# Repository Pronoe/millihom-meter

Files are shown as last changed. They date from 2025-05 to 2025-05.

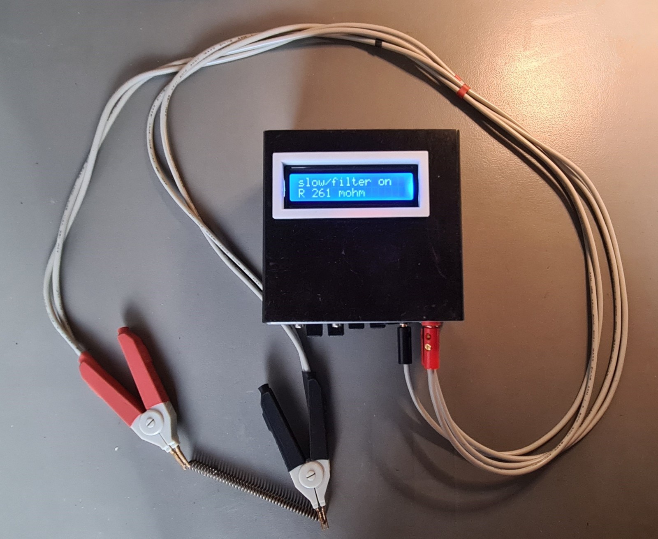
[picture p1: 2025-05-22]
pictures/20250522_191826 (FILEminimizer).jpg

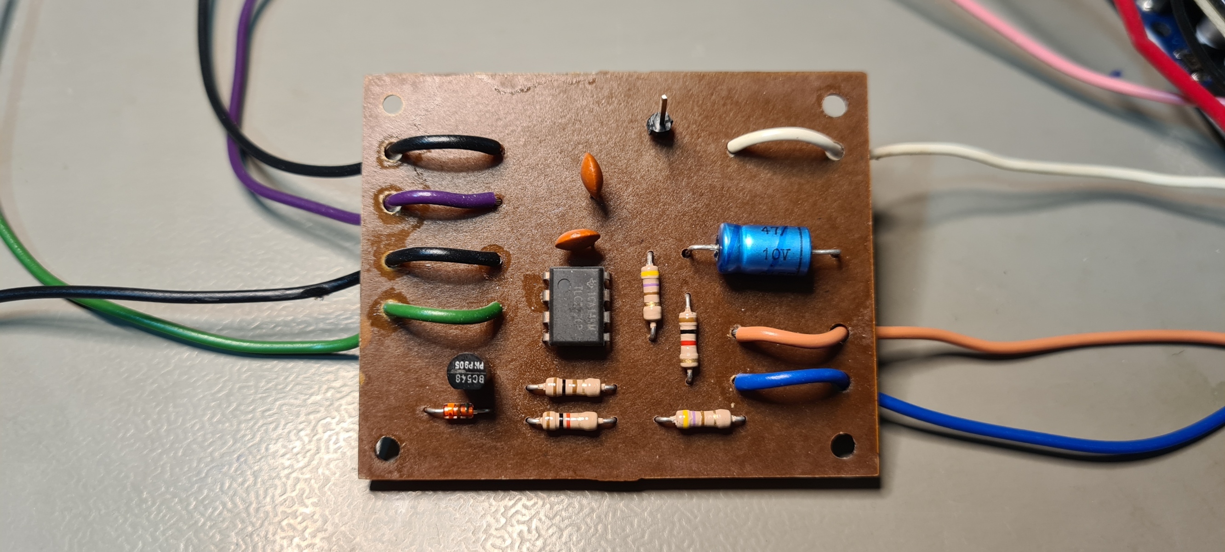
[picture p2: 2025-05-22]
pictures/20250503_223140 (FILEminimizer).jpg

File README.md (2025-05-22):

# milliohm-meter
Portable and low cost milliommeter with good performances

# Introduction
When you have to debug electronic systems or find failure on an electronic board or electrical system, you frequently need to locate short circuits.
Common multimeters  are generally limited down to 1 ohm in their measurement and this is not sufficient for efficient characterization and localization of a short circuit.
Below the 1 ohm domain, a milliohmmemeter is the required instrument but Industrial miiliohmmeters are expensive so I decided to build my own device.

# General design
I had viewed a good publication for a DIY milliohmmeter from the "Electro-bidouilleur" YouTube channel. The Elektor magazine sells also a add-on device for multimeters.
However this projects suffers several drawbacks:
-	need a separate multimeter for the measurement
-	provides no protection against excessive voltage on the device under test
-	do not use 4 wires measurement for better accuracy
The main characteristics of my design are:
-	use of a INA199 from Texas Instrument for the measurement
o	this is a Voltage-Output, Current-Shunt Monitor which need no additional component
o	provides very low offset voltage and very low drift
o	high accuracy gain
-	current source of 10.6 mA build with a ½ TLC272 which is a precision dual operational amplifier
-	voltage limiter with a BC548 transistor
-	use of and Arduino Uno board for:
o	output voltage measurement,
o	resistance computation from voltage measurement
o	initial zero compensation
o	full range calibration
-	use of a 2 lines x 16 characters LCD display shield for user interface
-	use of a a 1200 mAh LiPo battery combined with a step up converter/ battery charger  for portable operation
-	use of a "Kelvin" 4 wires cable for device connection

see detailed information in technical files

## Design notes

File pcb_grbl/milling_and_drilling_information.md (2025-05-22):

# Usinage PCB ampli milliohmmetre
Dimensions PCB : 61.6 x 48.9 mm
Entraxe trous de fixation : 54.0 x 41.3 mm
Routage PCB finalisé avec Kicad le 09/04/25
Prise en compte amélioration pads pour fil plus large, réutilisation maquette PCB INA199
Largeur piste 0.6 sauf au voisinage du INA199 : 0.4 mm
Isolation min : 0.4 mm
Utilisation plans de masse et Vcc avec isolation 0.4 mm.
Fichiers cnc générés avec Flatcam le 09/04/25, repris le 26/04/25 suite à 3 pistes oubliées dans Kicad
Fichiers gcode contrôlés avec utilitaire python le 09/04/25, recontrôlés le 26/04/25
Fichiers d'entrée Flatcam tournés de 90° pour que l'axe Y soit selon la plus grande longueur.
Origine usinage : en bas à gauche du PCB

# A faire dans cet ordre :
- fixer le PCB
- passer en mode avion
- charger PCB_milli-Edge_Cuts.gbr_cutout.nc pour avoir les contours du circuit
- faire le zero X et Y et noter le 0 machine
- monter fraise javelot et la sonde Z, faire le 0Z
- faire le height map après avoir validé auto pour reconnaitre les contours
- enlever la sonde Z
- appliquer couche d'huile
- lancer PCB_milli-B_Cu.gbr_iso.nc avec fraise javelot => isolation des pistes en 4 passes
- lancer PCB_milli-B_Cu.gbr_ncc.nc avec fraise javelot => nettoyage petits ilots de cuivre
- monter foret 0.8 mm et la sonde Z et faire le 0Z
- enlever la sonde Z
- lancer PCB_milli-PTH.drl_cnc_0.8.nc => perçage trous 0.8 mm
- monter foret 1 mm et la sonde Z et faire le 0Z
- enlever la sonde Z
- lancer PPCB_milli-PTH.drl_cnc_1.0.nc => perçage trous 1.0 mm
- monter foret 1.25 mm et la sonde Z et faire le 0Z
- enlever la sonde Z
- lancer PCB_milli-PTH.drl_cnc_1.25.nc => perçage trous 1.25 mm
- monter foret 2.5 mm et la sonde Z et faire le 0Z
- enlever la sonde Z
- lancer PCB_milli-PTH.drl_cnc_2.5.nc => perçage trous 2.5 mm
- monter foret 3 mm et la sonde Z et faire le 0Z
- enlever la sonde Z
- lancer PCB_milli-PTH.drl_cnc_3.0.nc => perçage trous 3.0 mm
- monter fraise corm shaped 0.95 et la sonde Z et faire le 0Z
- enlever la sonde Z
- lancer PCB_milli-Edge_Cuts.gbr_cutout.nc : découpe du PCB

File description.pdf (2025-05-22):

Introduction

When you have to debug electronic systems or find failure on an electronic board or electrical system, you frequently need to locate short circuits.

Common multimeters are generally limited down to 1 ohm in their measurement and this is not sufficient for efficient characterization and localization of a short circuit.

Below the 1 ohm domain, a milliohmmemeter is the required instrument but Industrial miiliohmmeters are expensive so I decided to build my own device.

General design

I had viewed a good publication for a DIY milliohmmeter from the "Electro-bidouilleur" (https://www.youtube.com/watch?v=fWgxbTQs47s&list=LL&index=22) YouTube channel. The Elektor magazine sells also a add-on device for multimeters.

However this projects suffers several drawbacks:

- need a separate multimeter for the measurement
- provides no protection against excessive voltage on the device under test
- do not use 4 wires measurement for better accuracy

The main characteristics of my design are:

- use of a INA199 from Texas Instrument for the measurement
- this is a Voltage-Output, Current-Shunt Monitor which need no additional component
- provides very low offset voltage and very low drift
- high accuracy gain
- current source of 10.6 mA build with a ½ TLC272 which is a precision dual operational amplifier
- voltage limiter with a BC548 transistor
- use of and Arduino Uno board for:
- output voltage measurement,
- resistance computation from voltage measurement
- initial zero compensation
- full range calibration
- use of a 2 lines x 16 characters LCD display shield for user interface
- use of a a 1200 mAh LiPo battery combined with a step up converter/ battery charger for portable operation
- use of a "Kelvin" 4 wires cable for device connection

Design details

One of the difficulties is that the INA199 is available only in a tiny SMD SC70 package and as I wanted to test the design with a breadboard, I had to build a SC70 adaptor to connect the INA199 to my breadboard.

I have made this adaptor by milling a PCB with a CNC 3018. Meanwhile I was also testing the ability to implement a SC70 adaptor with such a limited machine as the CNC 3018.

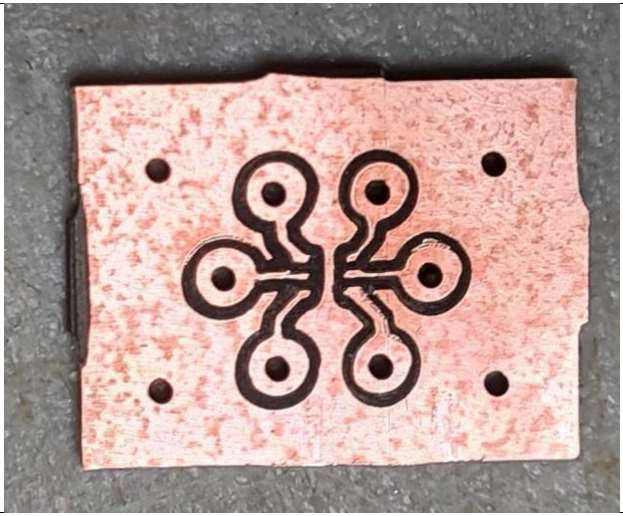
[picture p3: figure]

SC70 package adaptor for breadboard testing

This was a success and my breadboard confirmed the good behavior of the design.

This is the final schematic that I have implemented.

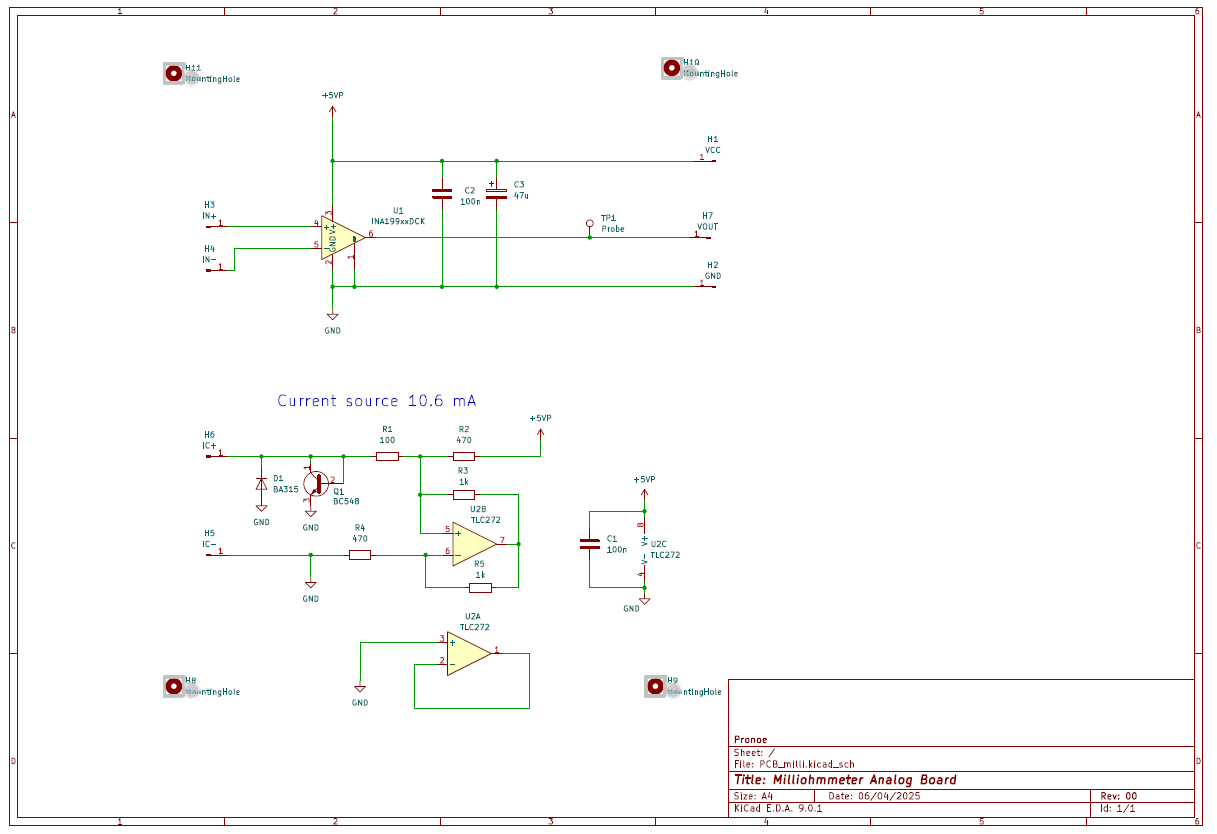
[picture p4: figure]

I have designed a single side PCB for this analog circuit, with Kicad and manufactured it by milling with my CNC 3018 router.

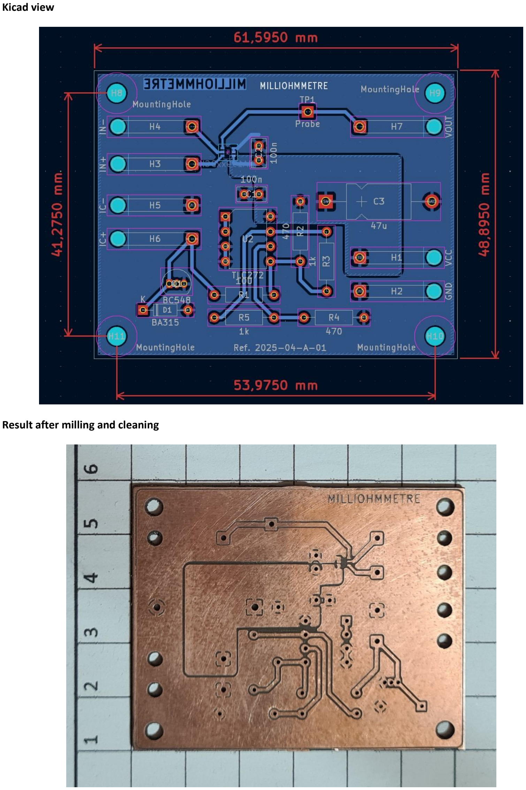
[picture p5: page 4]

Kicad view

Result after milling and cleaning

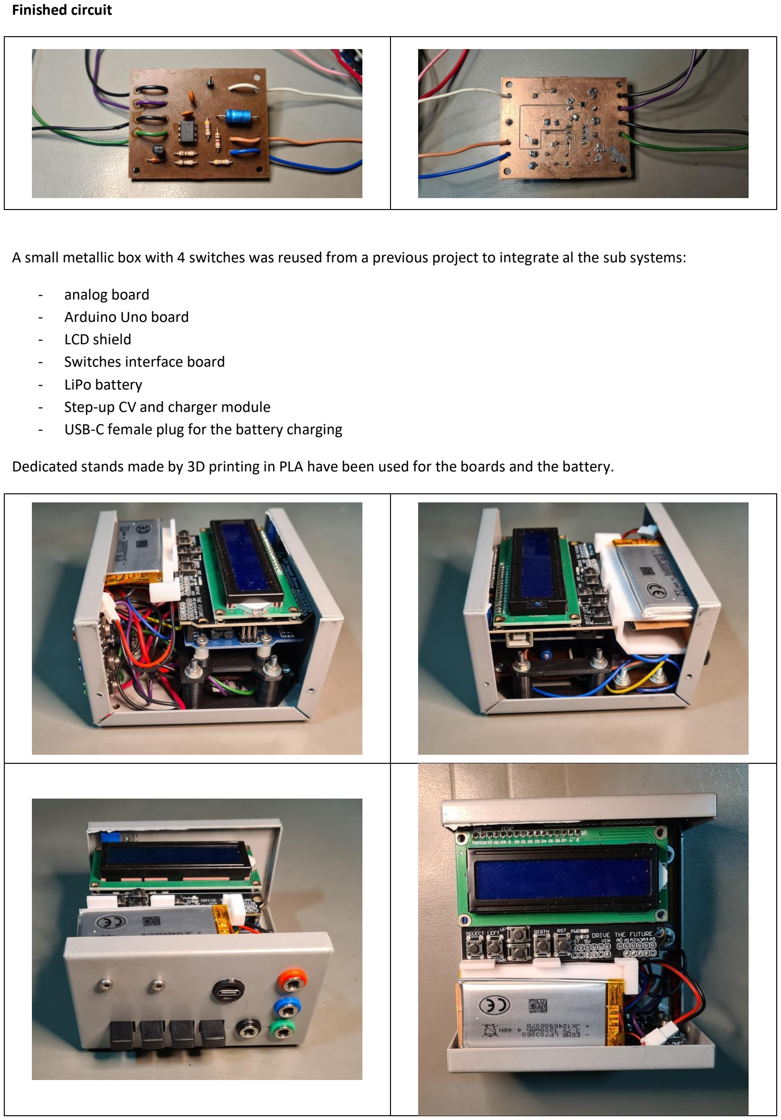
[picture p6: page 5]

Finished circuit

A small metallic box with 4 switches was reused from a previous project to integrate al the sub systems:

- analog board
- Arduino Uno board
- LCD shield
- Switches interface board
- LiPo battery
- Step-up CV and charger module
- USB-C female plug for the battery charging

Dedicated stands made by 3D printing in PLA have been used for the boards and the battery.

Arduino software

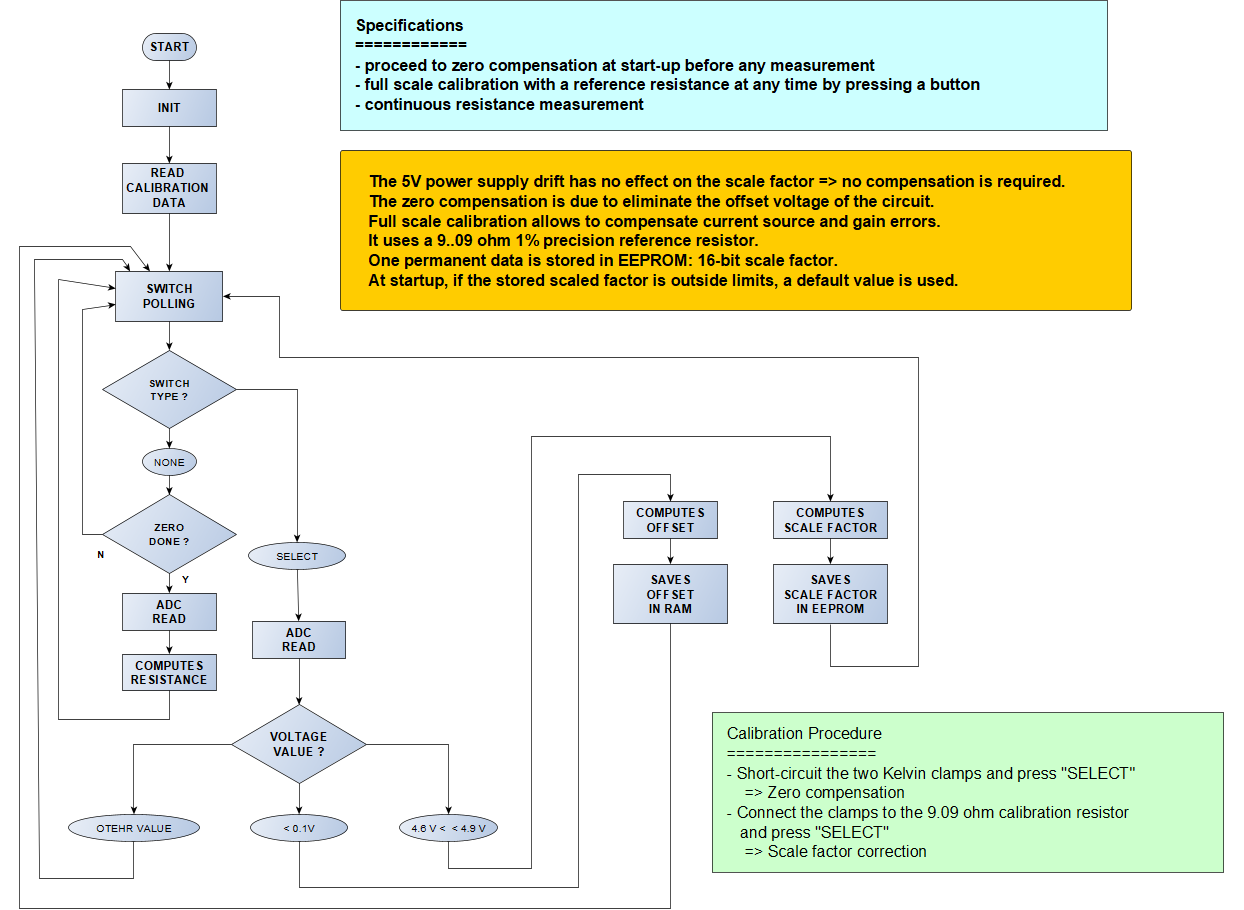
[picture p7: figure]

Equation Definition

Rmes = (Vmes - V0) x SF

With:

- Rmes = resistance measured value in mohm
- SF = Scale Factor in mohm/V
- Default SF = 1 / (50 x 10.55 e-3) = 1896 mohm/volt
- Vmes = ADC_read /1024 x Vcc

Vcc = 5.00 V (the exact value is irrelevant; it is compensated by SF)

Therefore, Rmes = (ADC_read - ADC_0) x SF1

SF1 = SF / 1024 x 5, nominal value 9.258 mohm / bit = 9258 µohm / bit

In practice, SF1 is stored in EEPROM in a 16 bits word (unsigned INT type).

Then, ADC_read x SF1 is calculated as a long INT and divided by 1000.

Zero Compensation

- Upon "SELECT" detection, Rmes is measured, and if Rmes < 100 mohm ((equivalent to ADC threshold of 11), this validates the zero compensation mode
- Then the current value of ADC_read is saved in ADC_0 variable
- While the initial zero compensation has not been done, a warning message reminds the user that zeroing must be performed

Scale factor calibration

- upon "SELECT" detection, Rmes is measured and if 8800 < Rmes < 9400 mohm (equivalent to ADC thresholds of 950 and 1015), this validates the calibration mode
- in this case, we compute the new value of SF1 = 9090000 / (ADC_read - ADC_0) and save it in EEPROM

Parameters

- EEPROM address for SF1 storage: #0
- Measurement frequency: 1 s (might be changed in future versions)
- Input switch polling rate: 100 ms (but the SELECT button can only be used once every second)
- At initialization:
- ADC_0 set to -1 at init, which determines that zero is not set
- SF1 read from EEPROM. If SF1 is outside the range [9700, 8800], SF1 is set to the default value of 9258

Resistance computation

- Calculation of SF1 and Rmes as 32-bit integers (+/- 2.1 109) and conversion to 16-bit integers after rounding to the nearest possible value.

Latest improvements

- Measurement rate selectable from 0.1 s and 1s
- Measurement filter selectable (IIR 1st order filter with coefficient 0.1)
- Implementation of 2 consecutive measurements and use of the 2nd only to optimize ADC precision

Future improvements

- Automatic standby to reduce battery drain
- Calculation and display of statistics for the last 100 measurements: min, max, average
- Use of the ATmega controller's "noise canceler" mode to reduce noise induced errors

Arduino code

//=======================================================================/
// Software for milliohmmeter board with Arduino UNO | /
// the board uses an INA199 IC for voltage amplification with low offset / // and a constant current source of 10.55 mA powered by Arduino Vcc (5V) / // The Arduino UNO board is fitted with a LCD 2x16 characters LCD dsplay /
// Software requirements: | /
// - continuous resistance measurement and result display at 1s rate | /
// - zero compensation when "SELECT" key depressed | /
// - scale factor calibration when "SELECT" key depressed and reference /
// | value of 9.09 ohm +/- 1% is connected to the input | /
// - calibration data saved in EEPROM | /
//=======================================================================/ // Author: Patrick SOUTY (Pronoe)
// Date of creation: 02/04/2025
// under GNU General Public License v3.0
// Versions:
// 1.0 - 02/04/2025 - initial version
// 2.0 - 08/05/2025 - use of external buttons following hardware integration
// 2.1 - 14/05/2025 - cleaning of code before publication and minor corrections
// 3.0 - 22/05/2025 - IIR filter mode added + double ADC measurement + measurement rate selection

//======================================================================================== ========/

String SW_name = "Milliohm";
String SW_version = "V3.0";
#include <LiquidCrystal.h> // using LiquidCrystal library

#include <EEPROM.h> | // using EEPROM library

// define EEPROM addresses used for SF1 and ADC_0 storage #define SF1_ADD 0
#define ADC_0_ADD 4

#define SF1_default 9258 // default scale factor value in µohm/bit

// define analog input for V(R) measurement
#define Vin A1 | // use A1 for INA199 output voltage measurement

#define polling_rate 200 // polling rate of buttons and switches in ms

// define variables used for resistance measurement
int meas_rate = 1000; | // delay between measurements
in ms
int ADC_read; | // used for ADC measurement
storage
int SF1; | // scale factor in µohm/bit
int ADC_0; | // ADC value for zero ohm
input (i.e. offset value)
int Rref = 9090; | // calibration resistance in
milliohm
int Rmeas; | // measured resistance value
in mohm
long Rmeas_long; | // for 32 bits computation of
Rmeas
long Rmeas_filtered; | // filtered value of Rmeas on
32 bits
bool filter_on; | // filter mode ON or OFF
int ADC_min = int((long(Rref) * 965) / long(SF1_default)); | // ADC lowest value for scale
factor calibration (nominal value -3.5%)
int ADC_max = int((long(Rref) * 1035) / long(SF1_default)); // ADC highest value for scale factor calibration (nominal value +3.5%)
int ADC_0_max = 11; | // ADC highest value for zero
compensation
int coeff_filt = 100; | // actual value of order 1
IIR filter multiplied by 1000 (i.e. 0.1 for the actual value)
int i; | // index for loops
unsigned long time; | // for time management of adc
sampling
unsigned long polling_time; | // for time management of
buttns and switch polling
bool keyProcessed; | // used to avoid multiple
processing of a single key pressed
bool test = false;
int ADC_test = 2; // used for test
String MyString;
String Blank = " | "; // used to clear a full LCD line
String current_rate = "slow/";

String current_filter = "filter off";
// select the pins used on the LCD panel
LiquidCrystal lcd(8, 9, 4, 5, 6, 7);
// define some values used by the panel and buttons
#define pushButton1 A2 | // gray wire - note: A2, A3 and A4 used as digital inputs

#define pushButton2 A3 | // yellow wire

#define switchButton A4 // green wire

int calSelect = 0;
int validateSelect = 0; // push button state - reserved for future use
int modeState = 0; | // stat of the mode button - reserved for future use

// reads HW push buttons and switch subroutine
void read_HW_buttons() {
calSelect = !digitalRead(pushButton1); validateSelect = !digitalRead(pushButton2); modeState = !digitalRead(switchButton);
if (test) {
Serial.print("buttons state : "); Serial.print(calSelect);
Serial.print(" ");
Serial.print(validateSelect); Serial.print(" ");
Serial.println(modeState);
}
}

void setup() {
// read calibration values in EEPROM
Serial.begin(115200);
ADC_0 = -1; | // negative value states that zero compensation has not been
done
EEPROM.get(SF1_ADD, SF1); // read SF1 value in EEPROM
if ((SF1 > 9700) || (SF1 < 8800)) {
SF1 = SF1_default;
}
// input buttons configuration pinMode(pushButton1, INPUT_PULLUP); pinMode(pushButton2, INPUT_PULLUP); pinMode(switchButton, INPUT_PULLUP);
// LCD display init
lcd.begin(16, 2); // start the LCD library lcd.display();
lcd.setCursor(0, 0);
MyString = SW_name + " " + SW_version; Serial.println(MyString);
Serial.println("Program started ..."); lcd.print(MyString); // print SW information lcd.setCursor(0, 1);
lcd.print("set zero & "
"SELECT"
"");
time = millis() + meas_rate; | // save next time to make measurement

polling_time = millis() + polling_rate; // save next time to poll buttons keyProcessed = false;
filter_on = false;
}

void loop() {
if (millis() >= time) {
// it's time to carry on measurement // ADC measurement
if (test) {
ADC_read = ADC_test;
} else {
ADC_read = analogRead(Vin); // samples input voltage - dummy read
ADC_read = analogRead(Vin); // samples input voltage - second read with stabilized input
}
if (test) {
Serial.print("SF1: ");
Serial.println(SF1);
}
time = time + meas_rate; // sets next sample time
if (ADC_0 > -1) {
// zero compensation has been done, then resistance value may be computed if (ADC_read == 1023) {
// overflow (open circuit or input resistance > 9.4 ohm) lcd.setCursor(0, 1);
lcd.print("Overflow | ");
} else {
Rmeas_long = long(SF1) * long(ADC_read - ADC_0); // computes with 32 bits in µohm Rmeas_filtered = (coeff_filt * (Rmeas_long - Rmeas_filtered) / 1000L + Rmeas_filtered);
if (filter_on) {
Rmeas = int((Rmeas_filtered + 500L) / 1000L); // round to the nearest value in mohm
} else {
Rmeas = int((Rmeas_long + 500L) / 1000L); // round to the nearest value in mohm }
// display value on second line
lcd.setCursor(0, 1);
MyString = "R " + String(Rmeas) + " mohm | ";
lcd.print(MyString); // dispaly measured value }
}
keyProcessed = false; // enable key processing
} | // end of measurement block
// buttons management
if (!keyProcessed && (millis() >= polling_time)) {
// lcd_key = read_LCD_buttons(); // read the buttons polling_time = millis() + polling_rate; // sets next polling time read_HW_buttons();
if (calSelect) // calibration button depressed
{
if (ADC_read < ADC_0_max) {

// zero compensation validated if (test) {
Serial.print("ADC_read: "); Serial.println(ADC_read);
}
ADC_0 = ADC_read; // save offset value lcd.setCursor(0, 1);
lcd.print(Blank); // remove warning message
if (test) { ADC_test = 960; }
} else if ((ADC_read > ADC_min) && (ADC_read < ADC_max) && (ADC_0 > -1)) {
// scale factor calibration validated
SF1 = int((long(Rref) * 10000L / long(ADC_read - ADC_0) + 5L) / 10L); // computes with 32 bits and round to the nearest value
lcd.clear();
MyString = "Cal " + String(SF1);
lcd.print(MyString); | // display scale factor on 1st line
EEPROM.put(SF1_ADD, SF1); // save SF1 value in EEPROM
} else {
// SELECT button depressed with wrong input conditions
// blink the display for warning
for (i = 0; i <= 5; i++) {
lcd.noDisplay();
delay(300);
lcd.display();
delay(300);
}
}
keyProcessed = true; // prevents further processing of the key until next sample time
}
// management of mode state switch
if (modeState) {
if (!filter_on) {
// a transition from OFF to ON of the state switch has been detected
filter_on = true; | // activate filtering
Rmeas_filtered = Rmeas_long; // initialize filtered value with last unfiltered value upon activation of filtered mode current_filter = "filter on ";
};
} else {
filter_on = false; // inhibits filter current_filter = "filter off";
}
if (validateSelect) {
// manage measurement rate
if (meas_rate == 1000) {
meas_rate = 100; // switch to 100 ms measurement rate current_rate = "fast/";
} else {
meas_rate = 1000; // switch to 1 s measurement rate current_rate = "slow/";
}
Serial.println(meas_rate);

}
// display current operation mode
if (ADC_0 > -1) {
MyString = current_rate + current_filter; lcd.setCursor(0, 0);
lcd.print(MyString);
}
keyProcessed = true; // prevents further processing of the key until next polling time
} | // end of !keyProcessed block
}

Measurement characteristics and test results

Voltage measurement resolution by ADC | 4.88 mV
Measuring current | 10.6 mA nominal
Resistance measurement resolution - without filter - with filter | 9,3 mohm 1 mohm
Measurement accuracy | ≈ 2% after zero and scale factor calibration
Measurement range | 9,5 ohm max
Voltage protection for the DUT | ≈ 700 mV
Battery autonomy | ≈ 13 h

Measurement of a 0.26 ohm precision shunt:

- without filter : commutes between 256 mohm and 263 mohm value
- with filter : 260 mohm +/- 1mohm

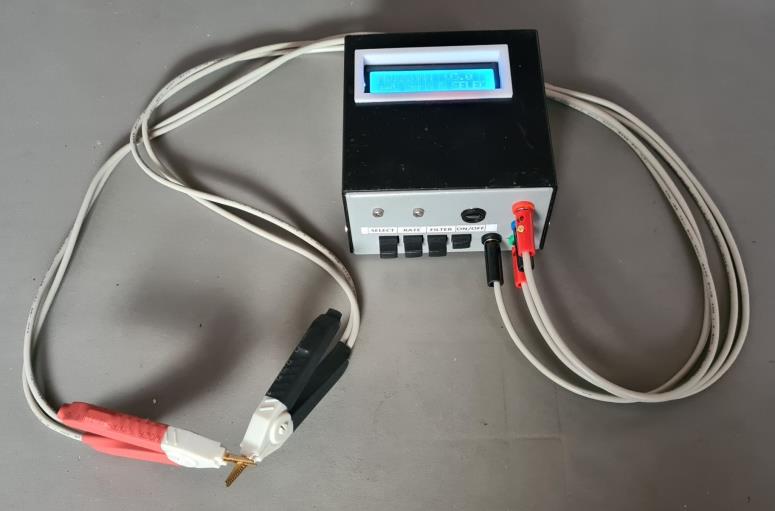
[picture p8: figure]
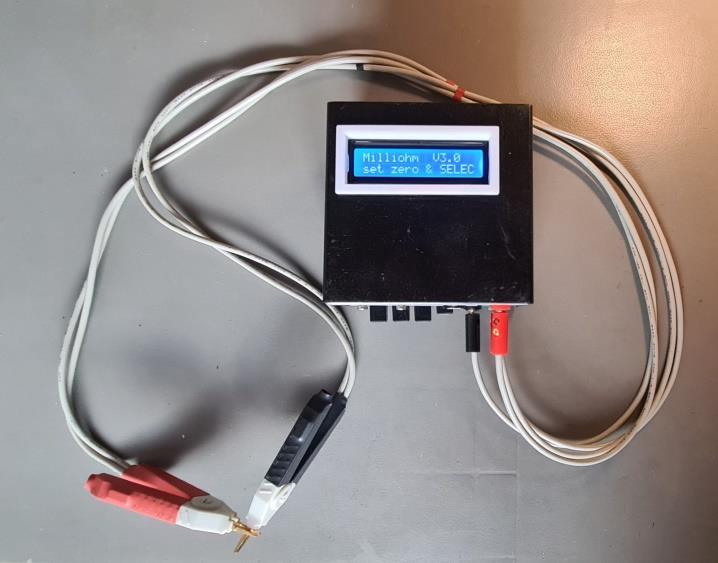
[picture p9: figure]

Zero ohm compensation

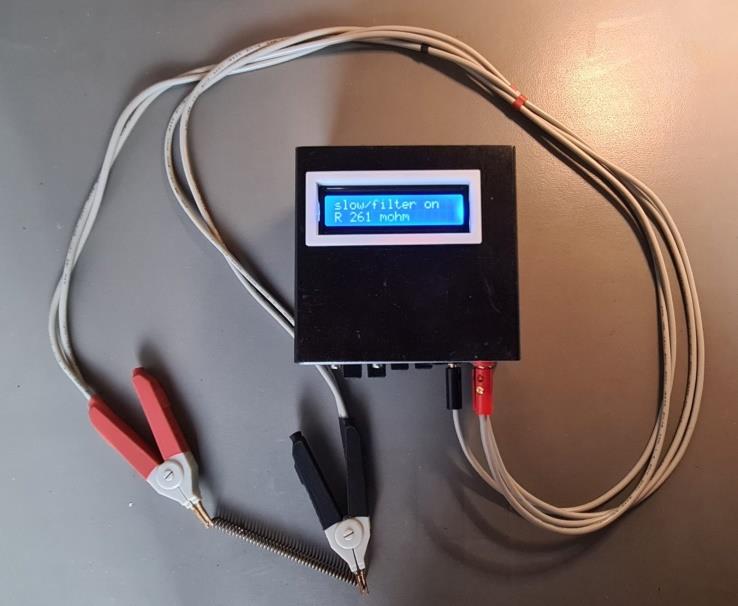
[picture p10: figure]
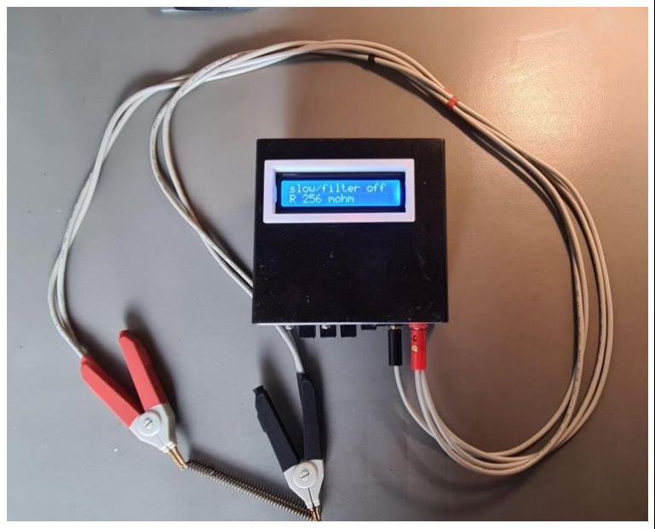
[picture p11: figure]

Measurement with filter activated | Measurement with no filter

Conclusion

This simple and low cost milliohmmeter provides very good performances and efficiency in a small and autonomous device.

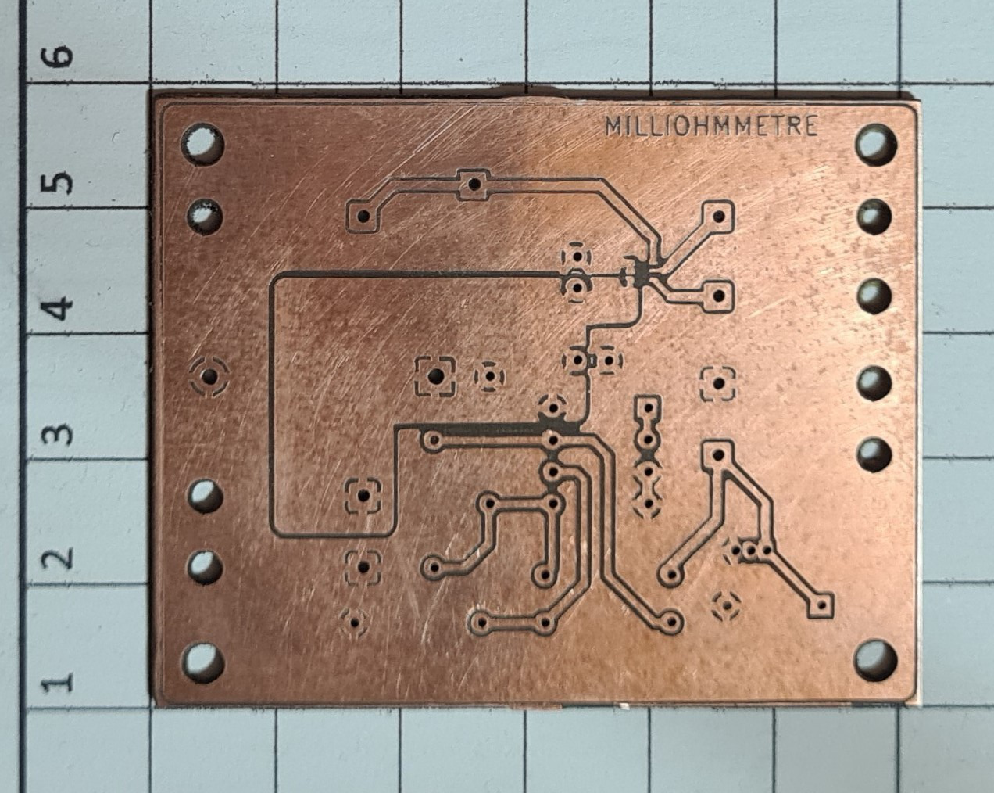
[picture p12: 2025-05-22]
pictures/20250501_212344 (FILEminimizer).jpg

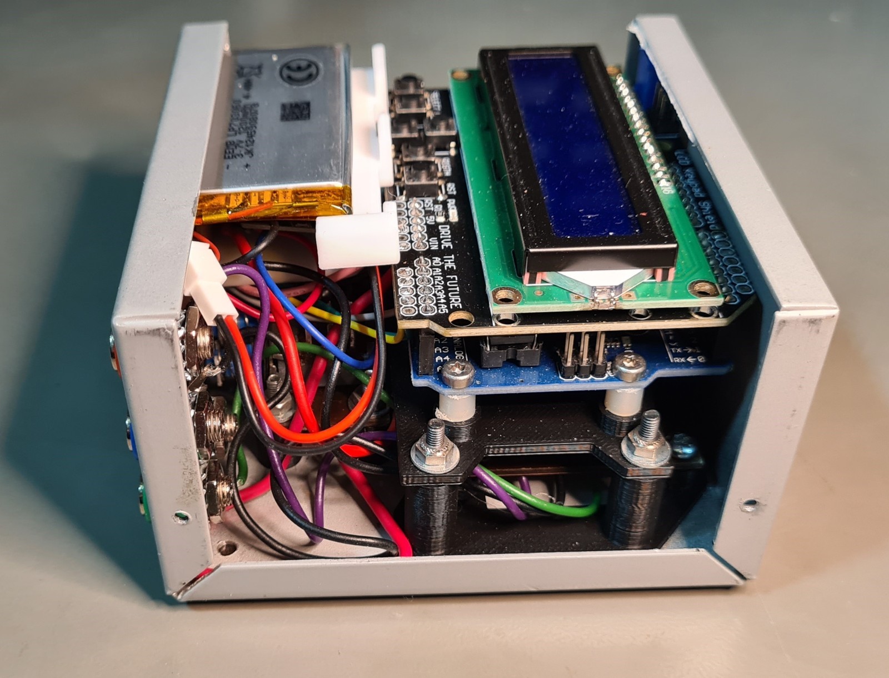
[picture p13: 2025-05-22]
pictures/20250512_212756 (FILEminimizer).jpg

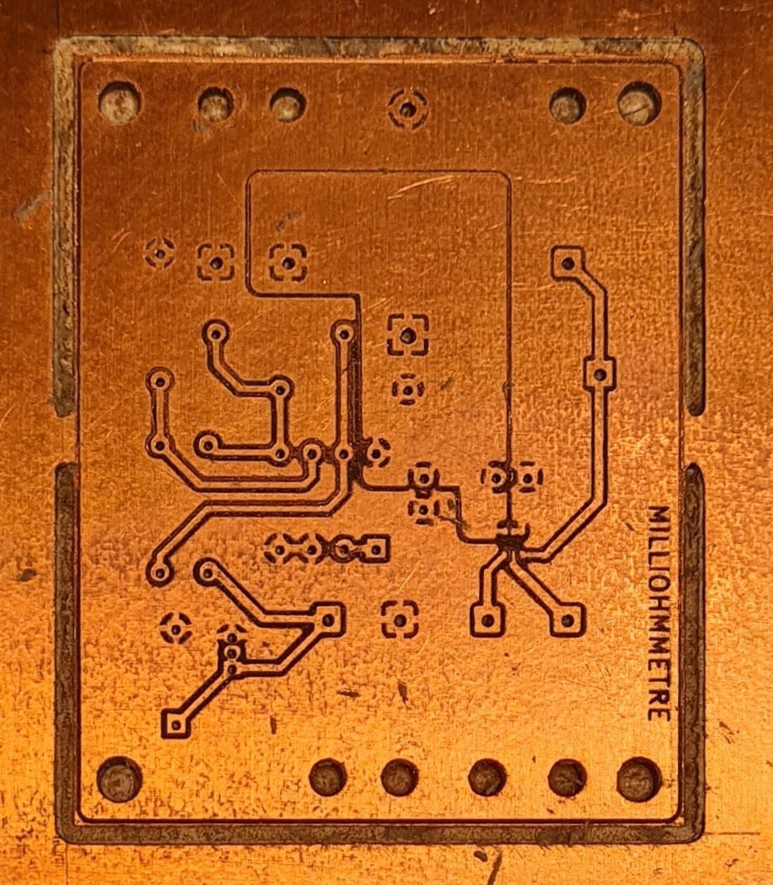
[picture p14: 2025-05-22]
pictures/20250430_234802 (FILEminimizer).jpg

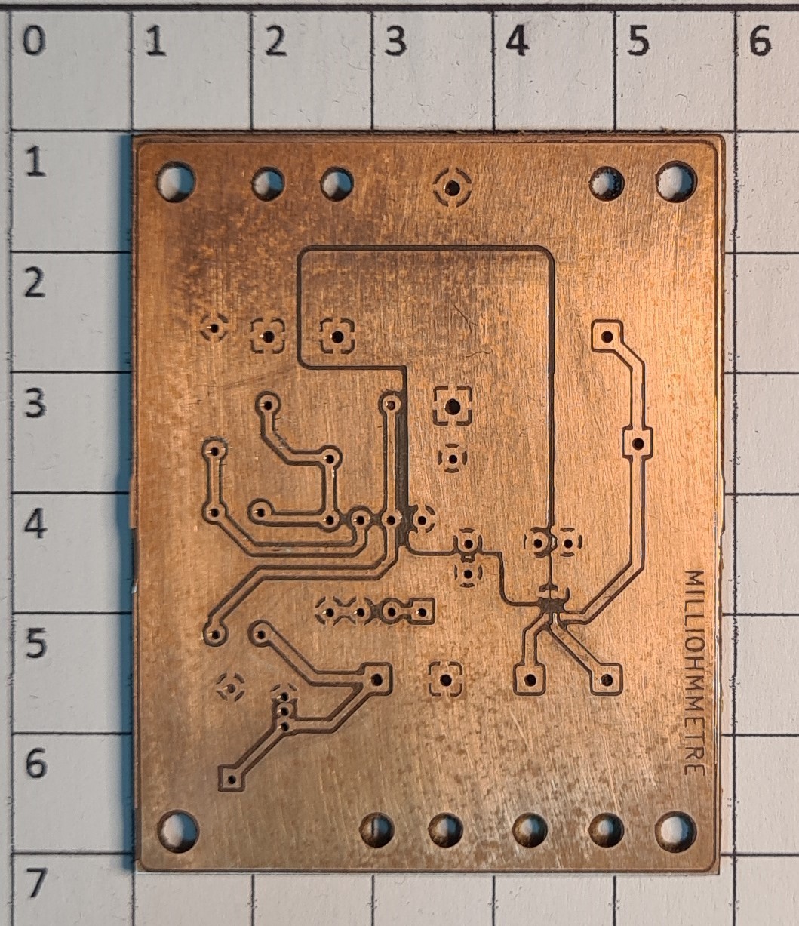
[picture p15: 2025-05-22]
pictures/20250501_212502 (FILEminimizer).jpg

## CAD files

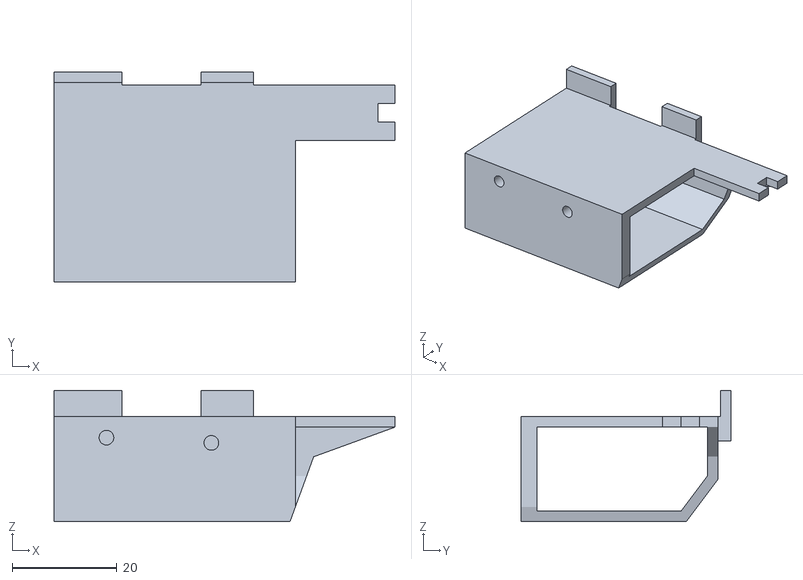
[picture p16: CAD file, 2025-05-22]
3D mechanical parts/lipo_batt_stand.stl
65.0 x 40.0 x 25.0

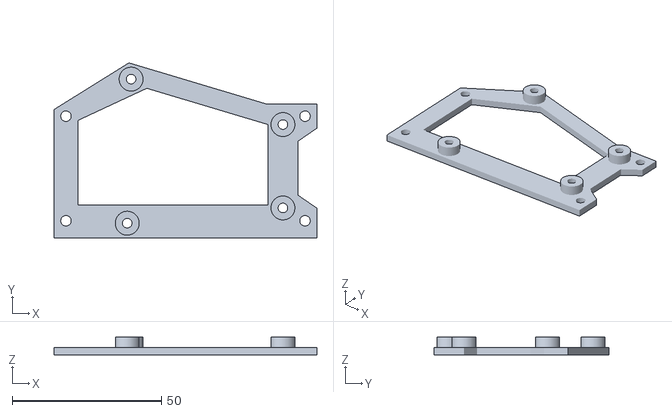
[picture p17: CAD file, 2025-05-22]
3D mechanical parts/upper_stand.stl
88.0 x 58.6 x 6.00

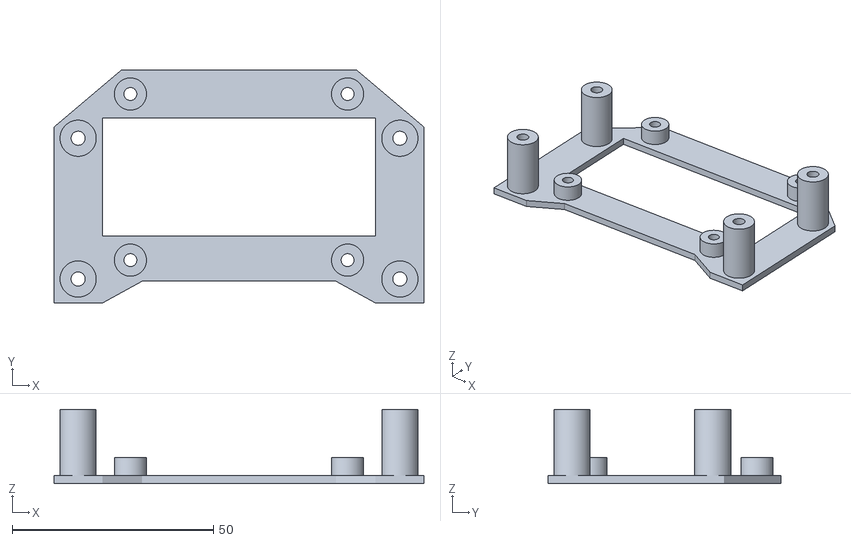
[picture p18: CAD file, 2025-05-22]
3D mechanical parts/bottom_stand.stl
92.0 x 58.0 x 18.5

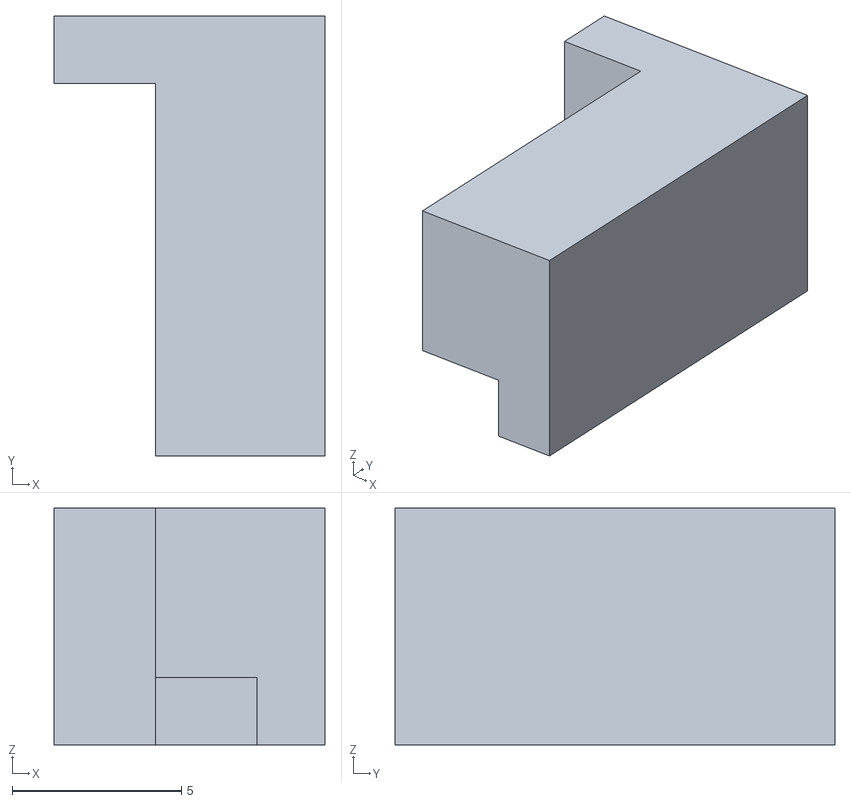
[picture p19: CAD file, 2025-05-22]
3D mechanical parts/battery_stop.stl
8.00 x 13.0 x 7.00

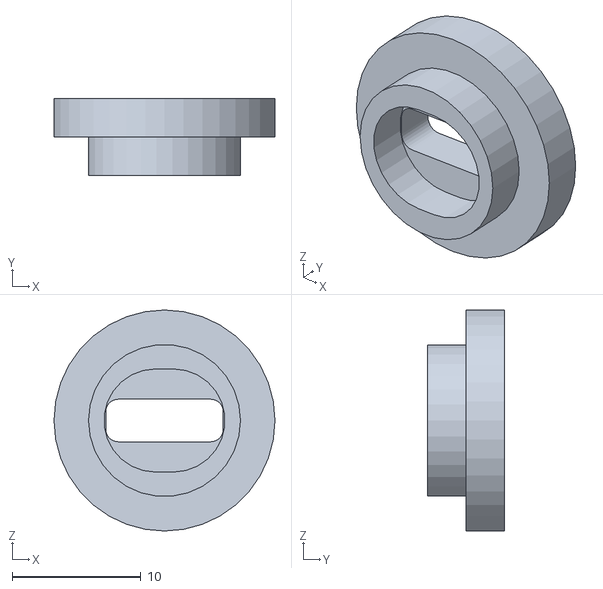
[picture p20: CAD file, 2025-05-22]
3D mechanical parts/USB_flange.stl
17.2 x 6.00 x 17.2

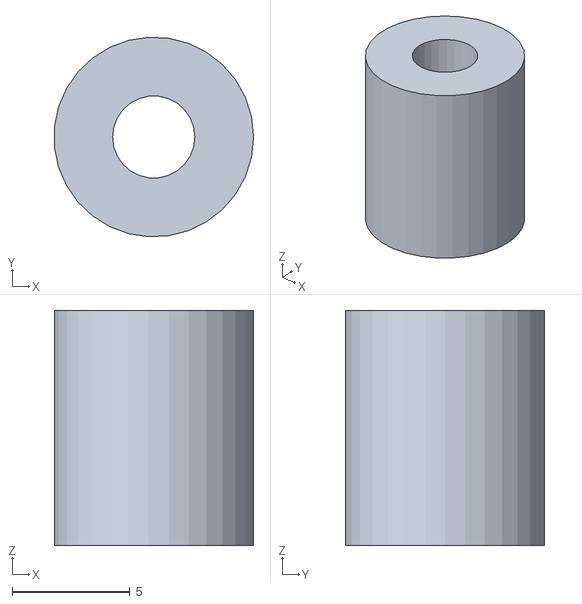
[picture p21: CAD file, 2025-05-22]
3D mechanical parts/pillar.stl
8.48 x 8.49 x 10.0

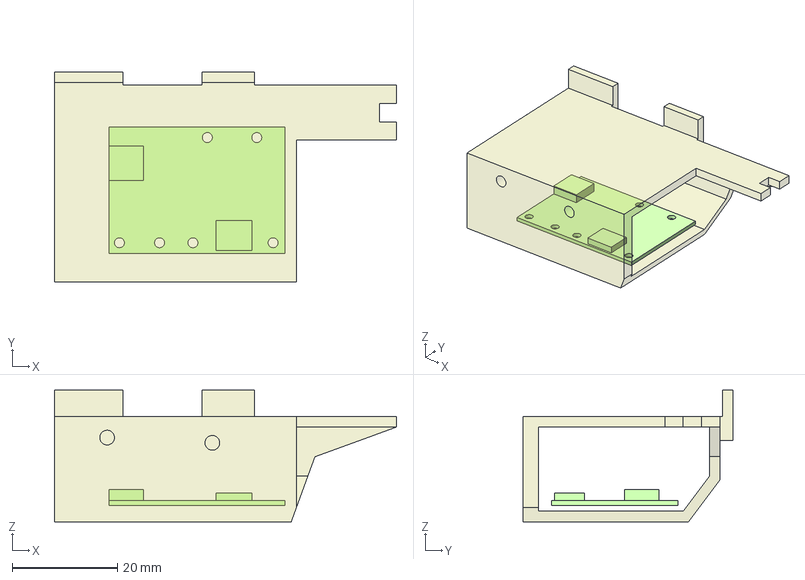
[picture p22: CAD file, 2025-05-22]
3D mechanical parts/milliohm_parts.FCStd
65.0 x 40.0 x 25.0 mm
support_lipo
Module chargeur

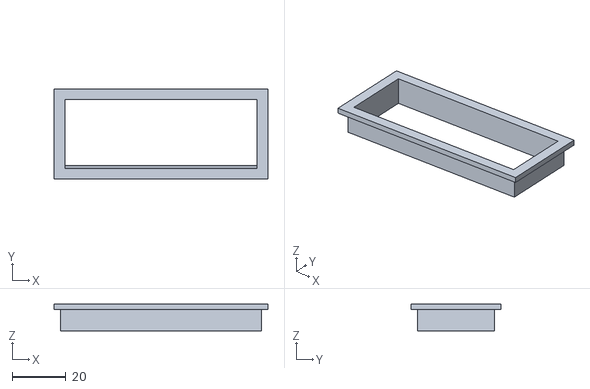
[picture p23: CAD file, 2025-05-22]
3D mechanical parts/LCD_frame.stl
79.5 x 33.5 x 10.0

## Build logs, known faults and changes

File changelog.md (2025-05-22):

9/05/2025   final HW version coupled with initial SW version V1
10/05/2025  SW code cleaning before github commit
22/05/2025  enhanced SW version with selectablemeasurement rate and filtering mode - github first commit

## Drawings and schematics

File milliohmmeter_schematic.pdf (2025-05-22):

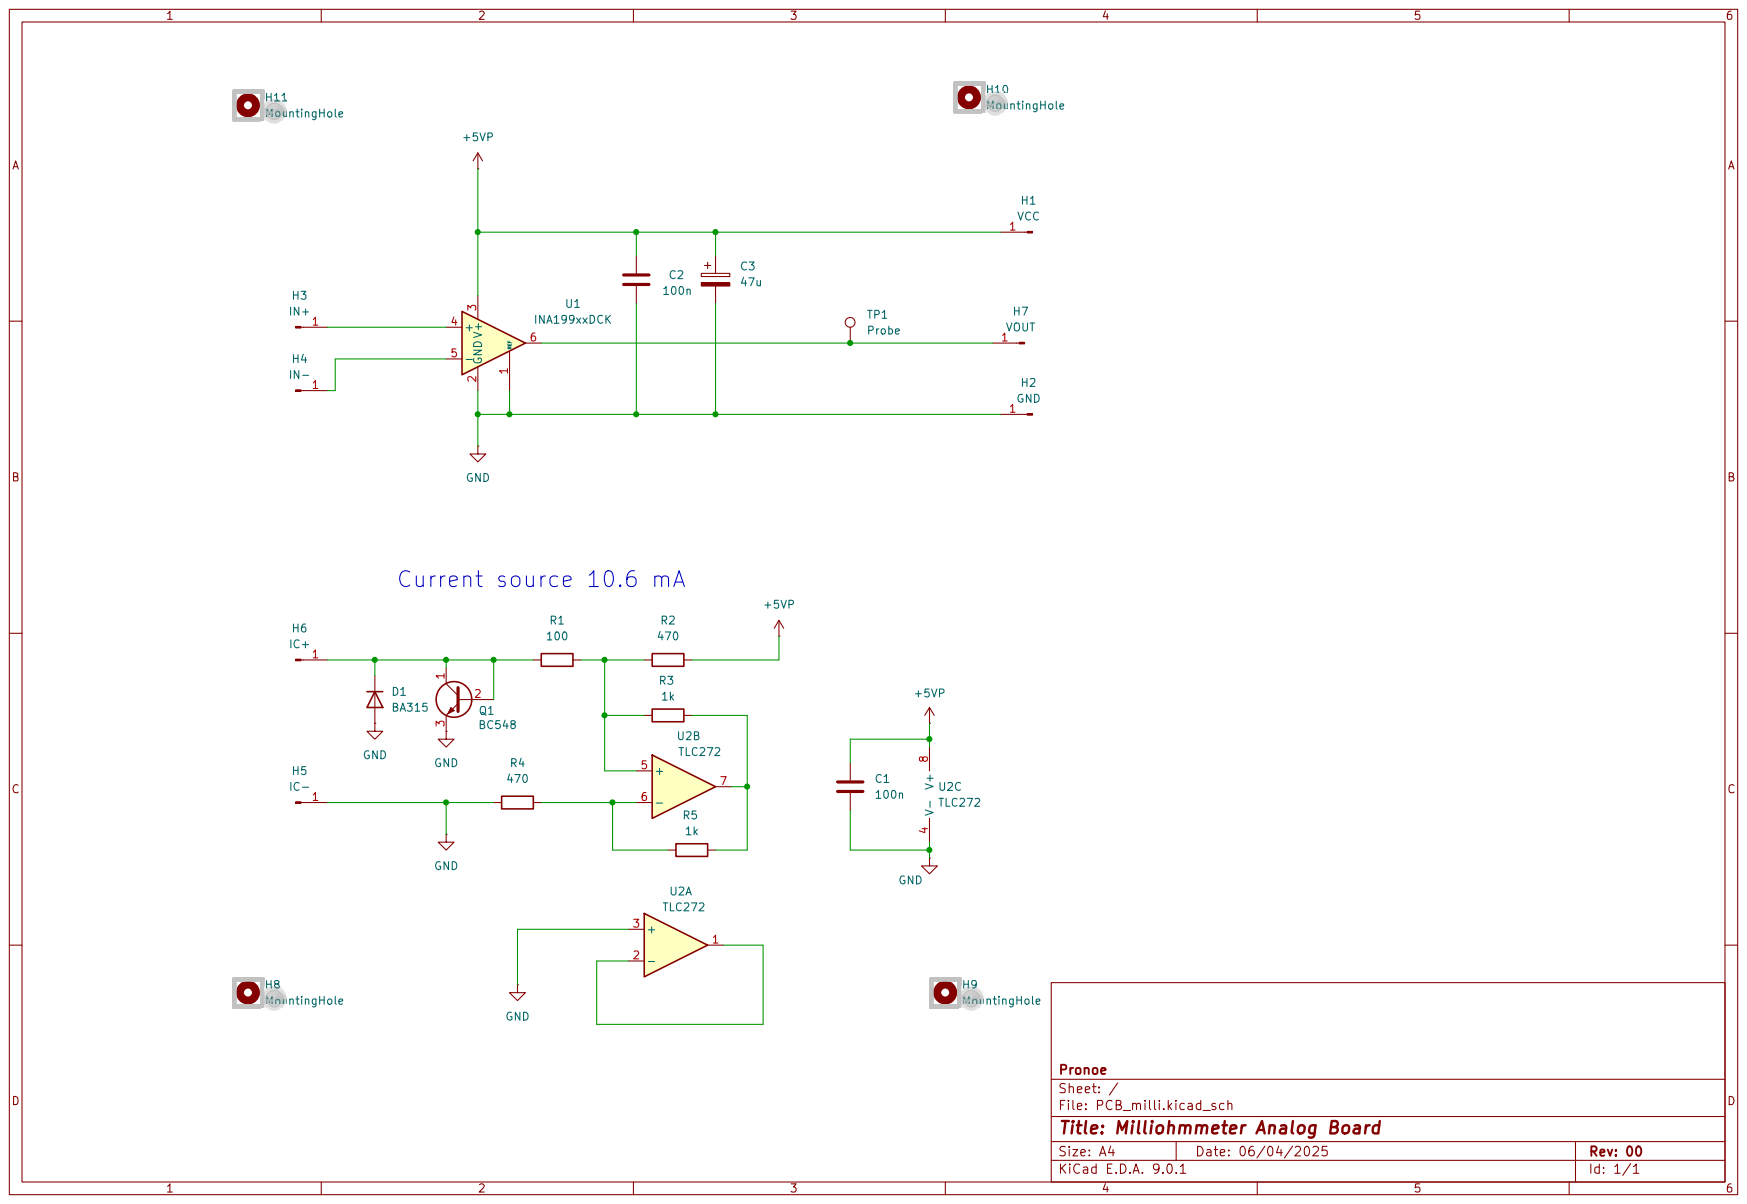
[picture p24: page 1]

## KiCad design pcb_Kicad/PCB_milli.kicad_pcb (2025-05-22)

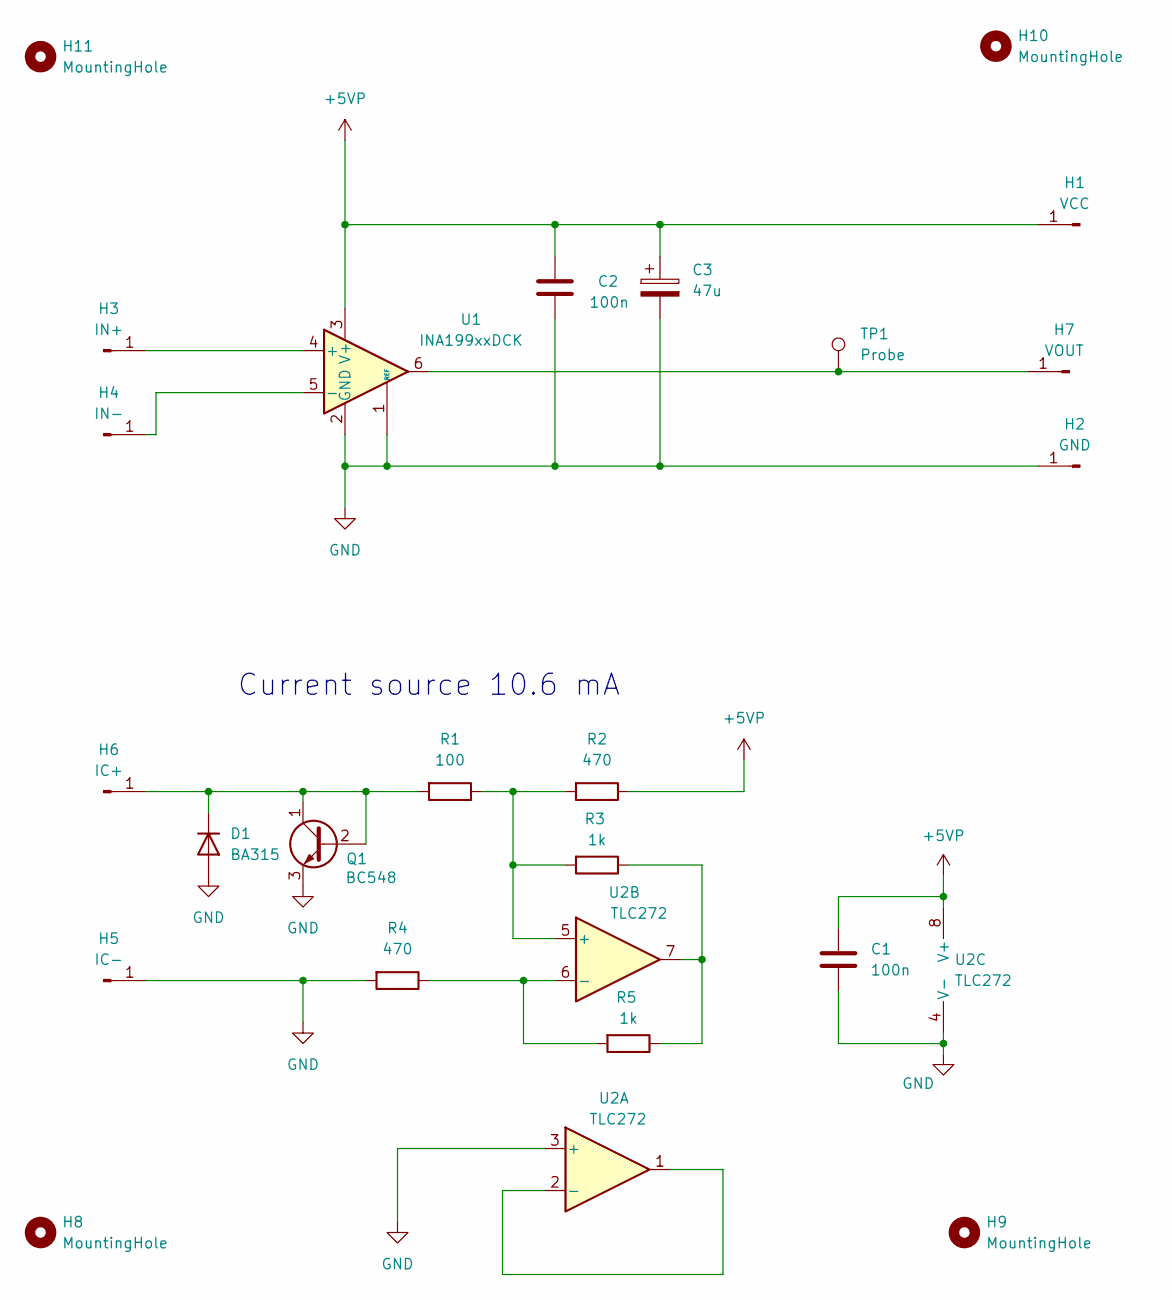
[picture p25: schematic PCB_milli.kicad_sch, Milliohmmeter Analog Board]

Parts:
C1, C2: 100n; C_Disc_D5.0mm_W2.5mm_P2.50mm
C3: 47u; CP_Axial_L11.0mm_D6.0mm_P18.00mm_Horizontal
D1: BA315; D_DO-35_SOD27_P7.62mm_Horizontal
H1: VCC; SolderWire-0.5sqmm_1x01_D0.9mm_OD2.1mm_Relief
H2: GND; SolderWire-0.5sqmm_1x01_D0.9mm_OD2.1mm_Relief
H3: IN+; SolderWire-0.5sqmm_1x01_D0.9mm_OD2.1mm_Relief
H4: IN-; SolderWire-0.5sqmm_1x01_D0.9mm_OD2.1mm_Relief
H5: IC-; SolderWire-0.5sqmm_1x01_D0.9mm_OD2.1mm_Relief
H6: IC+; SolderWire-0.5sqmm_1x01_D0.9mm_OD2.1mm_Relief
H7: VOUT; SolderWire-0.5sqmm_1x01_D0.9mm_OD2.1mm_Relief
H8, H9, H10, H11: MountingHole; MountingHole_3.2mm_M3
Q1: BC548; TO-92_Inline
R1: 100; R_Axial_DIN0207_L6.3mm_D2.5mm_P10.16mm_Horizontal
R2, R4: 470; R_Axial_DIN0207_L6.3mm_D2.5mm_P10.16mm_Horizontal
R3, R5: 1k; R_Axial_DIN0207_L6.3mm_D2.5mm_P10.16mm_Horizontal
TP1: Probe; TestPoint_THTPad_2.0x2.0mm_Drill1.0mm
U1: INA199xxDCK; SOT-363_SC-70-6
U2: TLC272; DIP-8_W7.62mm

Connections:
+5VP: C1.1, C2.1, C3.1, H1.1, R2.1, U1.3 (V+), U2.8 (V+)
GND: C1.2, C2.2, C3.2, D1.2 (A), H2.1, H5.1, Q1.3 (E), R4.2, U1.1 (REF), U1.2 (GND), U2.3 (+), U2.4 (V-)
unnamed: D1.1 (K), H6.1, Q1.1 (C), Q1.2 (B), R1.2
unnamed: H3.1, U1.4 (+)
unnamed: H4.1, U1.5 (-)
unnamed: H7.1, TP1.1, U1.6
unnamed: R3.1, R5.1, U2.7
unnamed: U2.1, U2.2 (-)
unnamed: R1.1, R2.2, R3.2, U2.5 (+)
unnamed: R4.1, R5.2, U2.6 (-)

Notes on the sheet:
Current source 10.6 mA

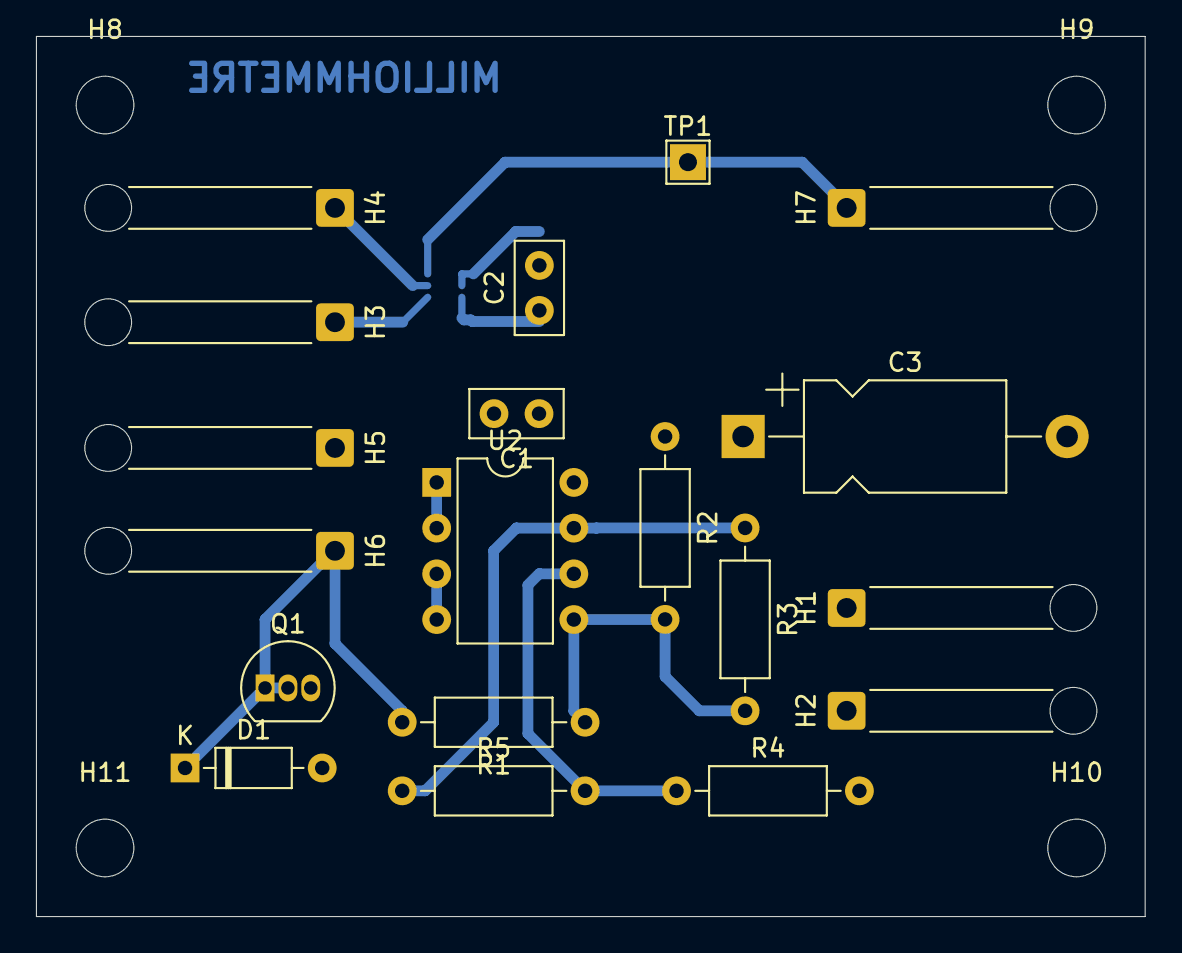
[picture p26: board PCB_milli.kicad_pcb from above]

Board: 2 copper layers, 61.6 x 48.9 mm, 24 parts (1 on the bottom side), 10 nets.
